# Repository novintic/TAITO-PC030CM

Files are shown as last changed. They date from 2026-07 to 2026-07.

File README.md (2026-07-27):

This is a Replica of the TAITO PC0030CM hybrid IC used to manage coin inputs and counters (that red ceramic package thingie). It is used on the Bubble Bobble CPU Board and other TAITO games.

If missing or corrupt, the board will report I/O error.

The coin-counter function has not been tested as we don't have any such counters.

Please understand that we are not able to offer any support. Use at your own risk. Thank you.

NOVINTIC 2026

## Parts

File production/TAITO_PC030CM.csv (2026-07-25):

Comment | Designator | Footprint | LCSC
1uF 50V | C1,C2,C3,C4 | Capacitor_SMD:C_0805_2012Metric | C5422
10nF | C6,C7,C8 | Capacitor_SMD:C_0805_2012Metric | C1710
1N4001 | D1,D2 | Diode_SMD:D_SMA | 1N4001
470R | R1,R7,R16,R19 | Resistor_SMD:R_0805_2012Metric | C17710
27R(1W) | R11,R12,R13,R14 | Resistor_SMD:R_2512_6332Metric | C25478
4.7K | R2,R8 | Resistor_SMD:R_0805_2012Metric | C17673
1K | R3,R9,R15,R20 | Resistor_SMD:R_0805_2012Metric | C17513
100R | R4,R10 | Resistor_SMD:R_0805_2012Metric | C17408
22K | R5,R6,R17,R18 | Resistor_SMD:R_0805_2012Metric | C101971
1N4733 | ZD1,ZD2,ZD3,ZD4 | Diode_SMD:D_SMA | C5266707

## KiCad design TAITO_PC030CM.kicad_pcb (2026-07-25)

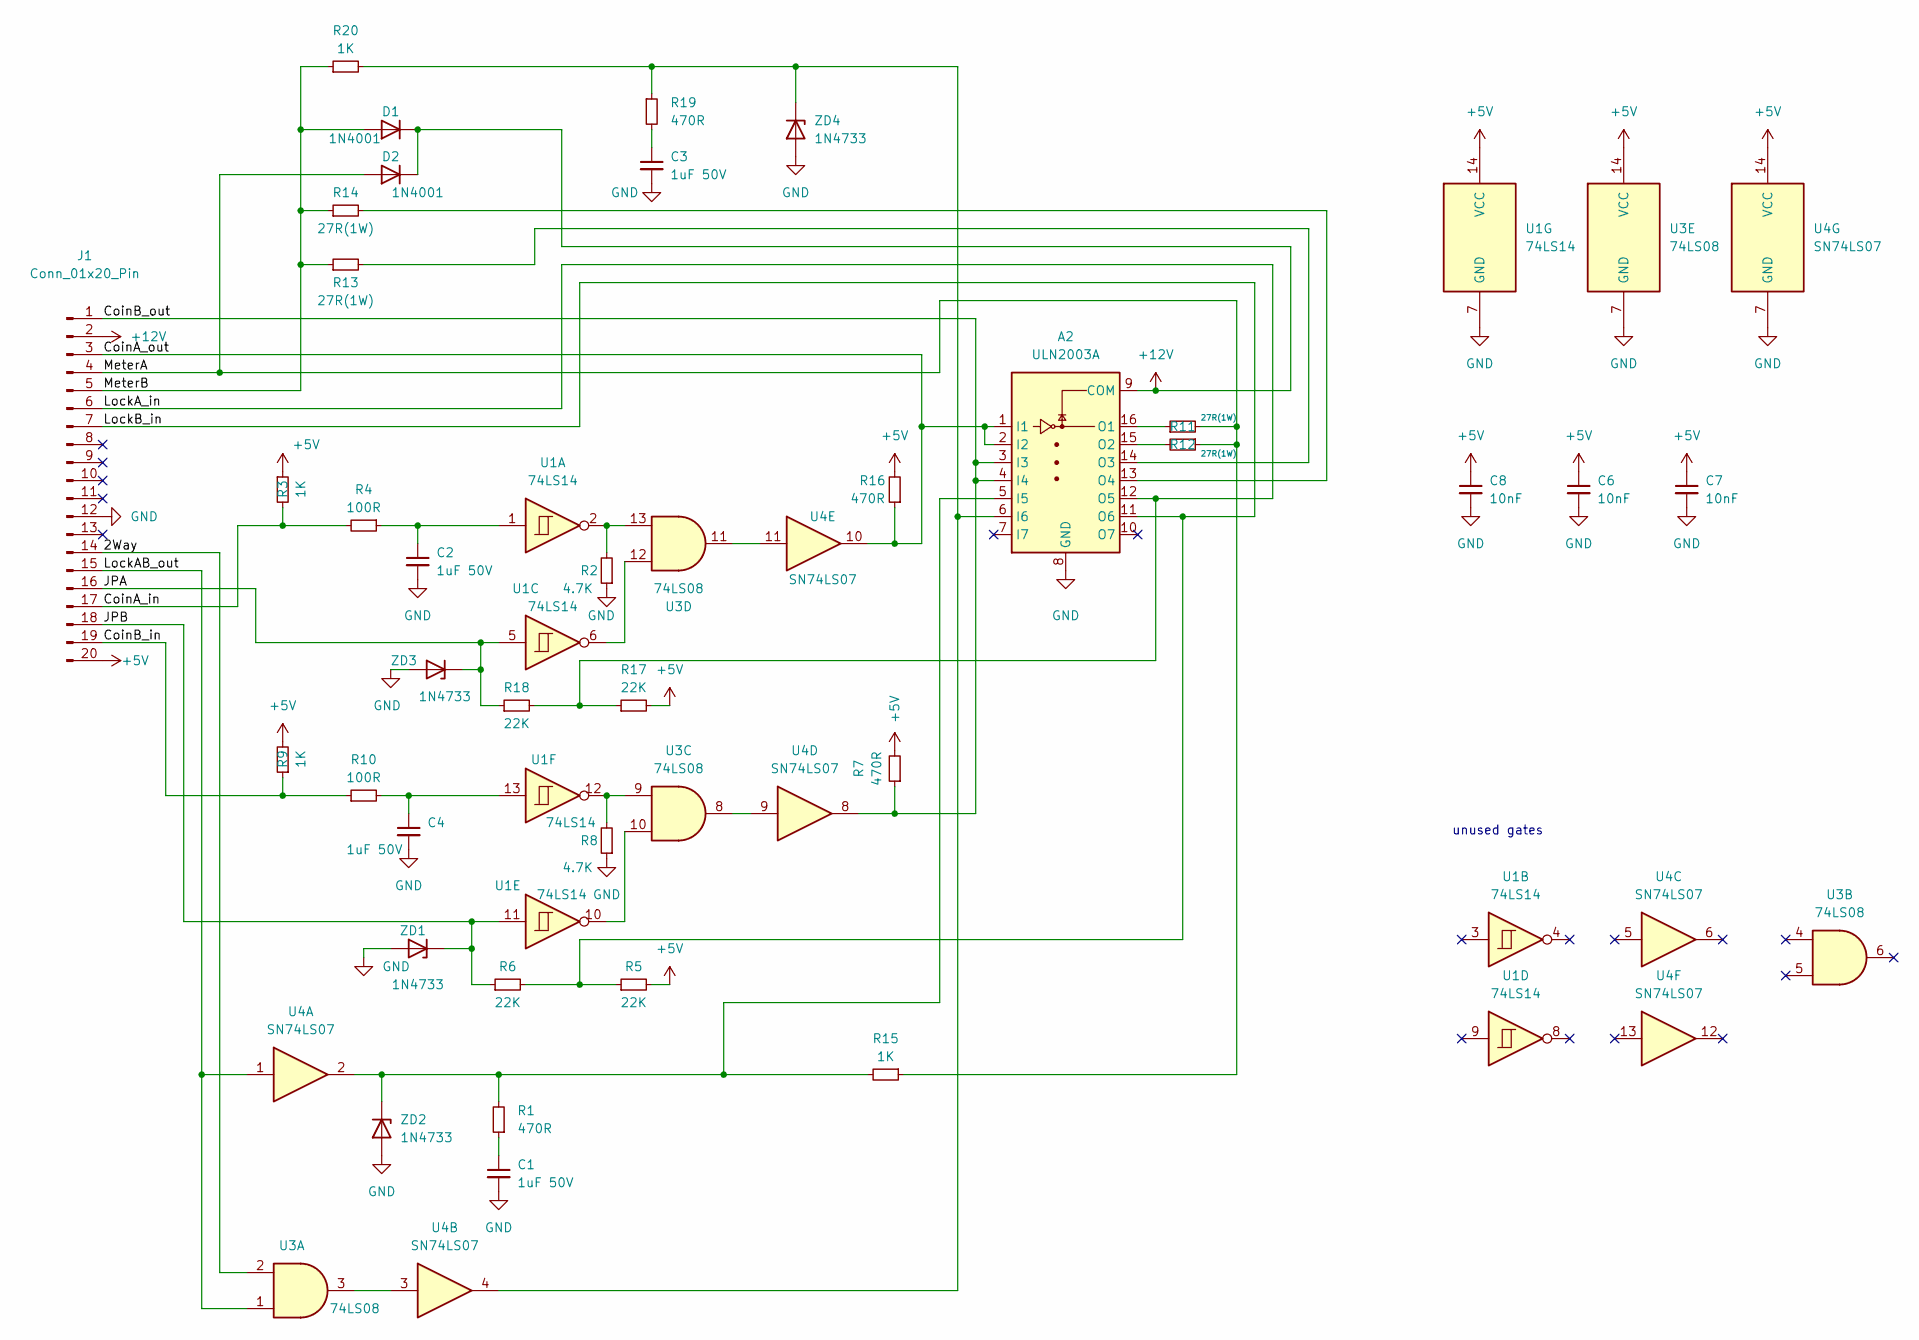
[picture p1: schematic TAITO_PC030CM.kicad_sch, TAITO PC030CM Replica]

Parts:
A2: ULN2003A; SOIC-16_3.9x9.9mm_P1.27mm; LCSC C181730
C1, C2, C3, C4: 1uF 50V; C_0805_2012Metric; LCSC C5422
C6, C7, C8: 10nF; C_0805_2012Metric; LCSC C1710
D1, D2: 1N4001; D_SMA; LCSC 1N4001
J1: Conn_01x20_Pin; PinHeader_1x20_P2.54mm_Vertical
R1, R7, R16, R19: 470R; R_0805_2012Metric; LCSC C17710
R2, R8: 4.7K; R_0805_2012Metric; LCSC C17673
R3, R9, R15, R20: 1K; R_0805_2012Metric; LCSC C17513
R4, R10: 100R; R_0805_2012Metric; LCSC C17408
R5, R6, R17, R18: 22K; R_0805_2012Metric; LCSC C101971
R11, R12, R13, R14: 27R(1W); R_2512_6332Metric; LCSC C25478
U1: 74LS14; SOIC-14_3.9x8.7mm_P1.27mm; LCSC C609750
U3: 74LS08; SOIC-14_3.9x8.7mm_P1.27mm; LCSC C521140
U4: SN74LS07; SOIC-14_3.9x8.7mm_P1.27mm; LCSC C513513
ZD1, ZD2, ZD3, ZD4: 1N4733; D_SMA_Handsoldering; LCSC C5266707

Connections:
+5V: C6.1, C7.1, C8.1, J1.20, R3.1, R5.2, R7.2, R9.2, R16.2, R17.2, U1.14 (VCC), U3.14 (VCC), U4.14 (VCC)
+12V: A2.9 (COM), D1.1 (K), D2.1 (K), J1.2
/2Way: J1.14, U3.2
/CoinA_in: J1.17, R3.2, R4.2
/CoinA_out: A2.1 (I1), A2.2 (I2), J1.3, R16.1, U4.10
/CoinB_in: J1.19, R9.1, R10.1
/CoinB_out: A2.3 (I3), A2.4 (I4), J1.1, R7.1, U4.8
/JPA: J1.16, R18.1, U1.5, ZD3.1 (K)
/JPB: J1.18, R6.1, U1.11, ZD1.1 (K)
/LockAB_out: J1.15, U3.1, U4.1
/LockA_in: A2.12 (O5), J1.6, R17.1, R18.2
/LockB_in: A2.11 (O6), J1.7, R5.1, R6.2
/MeterA: D2.2 (A), J1.4, R11.2, R12.1, R15.1
/MeterB: D1.2 (A), J1.5, R13.1, R14.1, R20.1
GND: A2.8 (GND), C1.2, C2.2, C3.2, C4.2, C6.2, C7.2, C8.2, J1.12, R2.1, R8.1, U1.7 (GND), U3.7 (GND), U4.7 (GND), ZD1.2 (A), ZD2.2 (A), ZD3.2 (A), ZD4.2 (A)
unnamed: A2.5 (I5), R1.2, R15.2, U4.2, ZD2.1 (K)
unnamed: A2.6 (I6), R19.1, R20.2, U4.4, ZD4.1 (K)
unnamed: A2.16 (O1), R11.1
unnamed: A2.15 (O2), R12.2
unnamed: A2.14 (O3), R13.2
unnamed: A2.13 (O4), R14.2
unnamed: C1.1, R1.1
unnamed: C2.1, R4.1, U1.1
unnamed: C3.1, R19.2
unnamed: C4.1, R10.2, U1.13
unnamed: R2.2, U1.2, U3.13
unnamed: R8.2, U1.12, U3.9
unnamed: U1.6, U3.12
unnamed: U1.10, U3.10
unnamed: U3.3, U4.3
unnamed: U3.8, U4.9
unnamed: U3.11, U4.11

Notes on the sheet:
unused gates

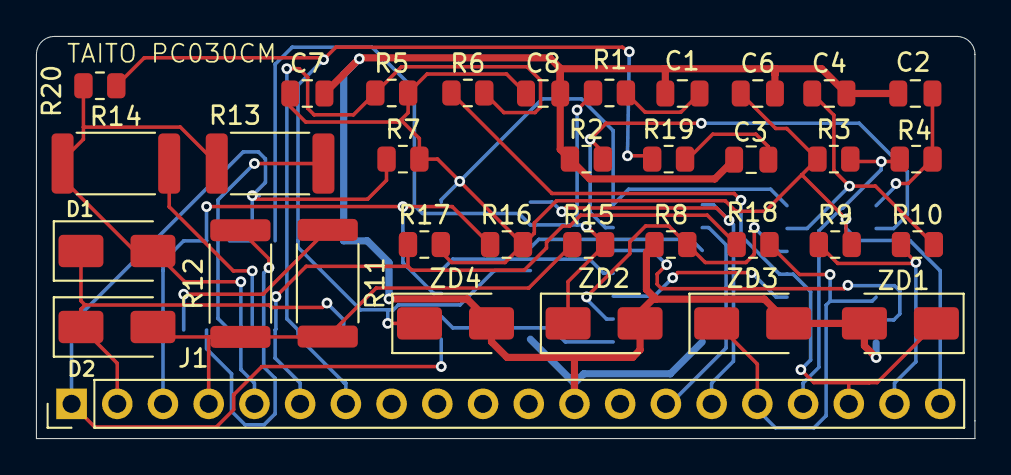
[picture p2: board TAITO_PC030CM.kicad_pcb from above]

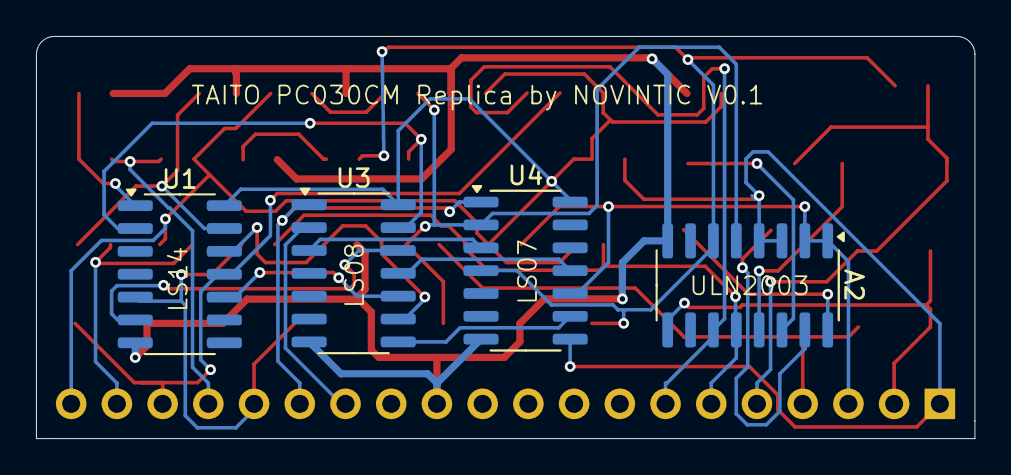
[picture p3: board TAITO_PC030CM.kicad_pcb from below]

Board: 2 copper layers, 52.1 x 22.3 mm, 38 parts (4 on the bottom side), 32 nets.
